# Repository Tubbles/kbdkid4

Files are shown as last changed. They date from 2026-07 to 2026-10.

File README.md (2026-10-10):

# kbdkid4

## Description

kbdkid4 is a split wireless keyboard, designed in [LibrePCB](https://librepcb.org).

Generated outputs (gerbers, BOM, schematic and assembly PDFs, STEP model) live in `output/v1/` and are also rebuilt by CI on every push, which publishes them as workflow artifacts and to [GitHub Pages](https://tubbles.github.io/kbdkid4/).

## 3D printed tray

`scripts/export_tray.py` builds a 3D-printable tray for the board from the exported STEP model, running FreeCAD headless. The board outline is located automatically (no hardcoded face indices); see the script's docstring for how and for the tray parameters.

    docker build -t freecad-headless -f scripts/freecad.Dockerfile scripts
    docker run --rm -v "$PWD":/work -w /work freecad-headless \
        freecadcmd scripts/export_tray.py --pass output/v1/kbdkid4_v1.step tray.stl [key=value ...] [flip]

The parameters (gap, wall, floor, depth, standoff and ledge dimensions) and their defaults are listed in the script's usage header and constants block.

`scripts/export_plate.py` likewise exports the switch plate: the kbdkid3 plate model (`resources/kbdkid3-plate-left.FCStd`), aligned onto the board by matching its switch cutouts to the board's switch grid, trimmed at the outer edges to fit the tray, extended over the microcontroller corner so it covers the whole board (with a conical recess on the underside at every soldered lead, 0.2 mm short of the top face, and a hole for the reset button), and cut with head-sized clearance holes at the board's mounting drills: the screws clamp the PCB onto the standoffs, the plate sits over their heads and is held down by the switches. The whole hole pattern (cutouts, screw holes, lead recesses, reset hole) is then shifted `pattern_shift` mm along +X relative to the outline, 0.25 mm by default: the first printed plates sat right in the tray but their holes drifted off the board's features toward the nice!nano side, and a plate printed with a 0.5 mm shift came out offset about as far the other way; the cause is still open. Last, `side_shave` mm (0.1 by default) comes off the plate's west and east edges, since the printed plate is a snug fit across the tray's width. The plate STL is written upside down (top face on the bed, lead recesses opening upward) so it prints as is without supports. CI exports both halves as the `plate-stl` artifact: `_Plate_Left.stl`, and `_Plate_Right.stl` mirrored across the board's center line (the word `right`).

CI runs this against the freshly generated STEP and uploads the result as the `tray-stl` workflow artifact.

CI exports both halves as the `tray-stl` artifact: `_Tray_Left.stl` as described, and `_Tray_Right.stl` built with the board's other side up (the word `right`), where the right half's switches and hotswap sockets sit, then turned over so it prints opening-up. That is not a mirror of the left tray: the right half's sockets do not reach the board edge, so that tray has no ledge notches.

## 3D printed PCB replica

`scripts/export_pcb.py` exports a printable stand-in for the bare board, for test-fitting the tray, plate, switches and screws before the fabricated boards arrive: the outline extruded to the board thickness with every drill hole, no components. Printed parts come out slightly larger than modelled, so the replica is pulled in by `pull_in` (default 0.2 mm) per side: the outline moves inward and every hole grows outward by that much. The thickness stays as modelled unless overridden with `thickness=`.

    docker run --rm -v "$PWD":/work -w /work freecad-headless \
        freecadcmd scripts/export_pcb.py --pass output/v1/kbdkid4_v1.step pcb.stl [right] [pull_in=0.2] [thickness=1.6]

CI uploads both halves as the `pcb-stl` artifact: `_Pcb_Left.stl`, and `_Pcb_Right.stl` mirrored across the board's center line (the word `right`). A bare board turned over would be its own mirror image, but a print is not: its bed side and its top side come out with different surfaces.

## License

See [LICENSE.txt](LICENSE.txt).

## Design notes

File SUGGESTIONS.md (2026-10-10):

# Suggestions

Ideas noticed during work, not yet asked for. Strike or promote as you see fit.

- **The nice!nano's board edge clears the tray ledge by only 0.03 mm.** With the nano under the board (`U1`, flipped), its PCB reaches to 0.63 mm inside the board's north edge, while the 1.0 mm ledge minus the 0.4 mm gap reaches 0.6 mm under the board edge (`scripts/export_tray.py`, `DEFAULT_LEDGE_WIDTH_MM`, `DEFAULT_GAP_MM`). The USB window removes the ledge over its 14 mm width, but the nano is 17.8 mm wide, so 2 mm at each end still face the ledge at 3.85 to 5.25 mm above the floor. Options: a narrower ledge (`ledge_width=0.9` or less), no ledge along that stretch, or the nano 0.3 mm further south on the board. Measured on LibrePCB's populated STEP export on 2026-09-27; not changed because it is a design choice between the ledge and the nano's position.
- **The west column's hotswap socket tabs end 0.17 mm from the tray wall.** Each PG1350 socket tab reaches 0.23 mm past the board outline (LibrePCB's placement of the package model, measured on the populated STEP export, 2026-10-08) and the wall sits `gap` = 0.4 mm outside the outline (`scripts/export_tray.py`, `DEFAULT_GAP_MM`). The ledge notches clear the tabs, but a print that comes out a little tight will rub there first. `gap=0.5` on the command line widens the whole cavity by 0.1 mm; the alternative is a shallow recess in the wall at the four notches. Left alone because the printed tray has not been tried yet.
- **The plate STL is not a closed mesh.** `scripts/export_plate.py` meshes the plate as a compound of touching cell solids (plus the tab and now the corner slab), so the STL carries coincident internal walls at every cell boundary: FreeCAD reports it non-manifold with hundreds of self-intersections, for the July 2026 export and the current one alike (the tray and PCB replica STLs are clean). Slicers have evidently coped so far. Fusing the solids once (`multiFuse` plus `removeSplitter`, which `drill_holes` already does for its connectivity check) before `export_stl` would give a single closed shell. Noticed 2026-10-08 while verifying the corner extension; left alone because it changes the shipped mesh of a part that already prints.
- **The printed plate's holes drift about 1 mm toward the nice!nano side over the plate's width; the cause is not found.** Checked 2026-10-09: `boards/board_1.1/board.lp` has every switch pitch at exactly 19.05 mm, the committed Excellon files put the 3.4 mm switch drills and the 2.4 mm mounting drills at the same positions, the kbdkid3 plate model's cutouts match the switch grid to 0.0005 mm, the exported plate STL has every cutout, screw hole and the reset hole at its design x within 0.08 mm, and the tray STL's standoff bores sit at the mounting drills to 0.001 mm. Both parts were printed unscaled. A 1 mm drift at 125 mm is 0.8 %, the size of a print scale or shrinkage error, but a plate shrunk that much should sit loose in the tray, which it does not. `pattern_shift` in `scripts/export_plate.py` corrects it empirically: a 0.5 mm shift came out offset about as far the other way (printed 2026-10-10; a linear 1 mm drift would have left both ends 0.5 mm off in opposite directions instead), so the default is 0.25 mm now. To find the cause, measure: the printed plate's width (design 135.05 mm for the plates printed so far, 134.85 mm since the side shave of 2026-10-10) and the span from the left edge of the bottom-left cutout to the right edge of the thumb cutout (design 128.4 mm), the PCB's two bottom mounting holes centre to centre (design 95.57 mm), and the printed tray's outer width (design 137.02 mm).

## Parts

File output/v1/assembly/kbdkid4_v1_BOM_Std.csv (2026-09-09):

Quantity | Designators | Package | Value | MPN | Manufacturer
50 | D100, D101, D102, D103, D110, D111, D112, D113, D120, D121, D122, D123, D130, D131, D132, D133, D140, D141, D142, D143, D150, D151, D152, D153, D163, D203, D210, D211, D212, D213, D220, D221, D222, D223, D230, D231, D232, D233, D240, D241, D242, D243, D250, D251, D252, D253, D260, D261, D262, D263 | SOD3717X135 | Diode SOD123
2 | DS1, DS2 | NICE_NICEVIEW | nice!view
2 | J1, J2 | JST_PH_S2B-PH-K_1x02_P2.00mm_Horizontal
54 | JP1, JP2, JP3, JP4, JP5, JP6, JP7, JP8, JP9, JP10, JP11, JP12, JP13, JP14, JP15, JP16, JP17, JP18, JP19, JP20, JP21, JP22, JP23, JP24, JP25, JP26, JP27, JP28, JP29, JP30, JP31, JP32, JP33, JP34, JP35, JP36, JP37, JP38, JP39, JP40, JP41, JP42, JP43, JP44, JP45, JP46, JP47, JP48, JP49, JP50, JP51, JP52, JP53, JP54 | SOLDER_JUMPER_2P
2 | S1, S2 | ALPSALPINE_SSSS811101 | SSSS811101
2 | S3, S4 | ESWITCH_TL3315NF100Q | Pushbutton Momentary NO (ESWITCH_TL3315NF100Q)
50 | S100, S101, S102, S103, S110, S111, S112, S113, S120, S121, S122, S123, S130, S131, S132, S133, S140, S141, S142, S143, S150, S151, S152, S153, S163, S203, S210, S211, S212, S213, S220, S221, S222, S223, S230, S231, S232, S233, S240, S241, S242, S243, S250, S251, S252, S253, S260, S261, S262, S263 | KHA-PG1350 | PG1350 Kailh Choc V1
2 | U1, U2 | NICE_NICENANO | nice!nano v2.0

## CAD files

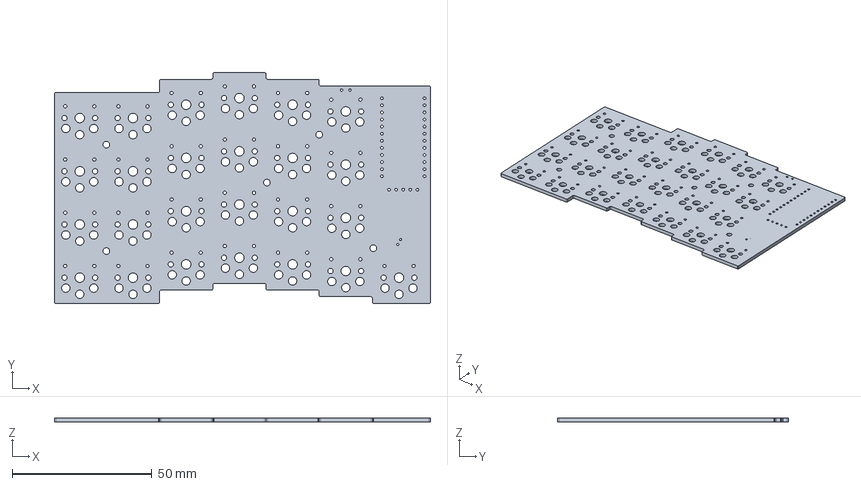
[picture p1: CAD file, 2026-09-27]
output/v1/kbdkid4_v1.step
134.6 x 82.6 x 1.60 mm

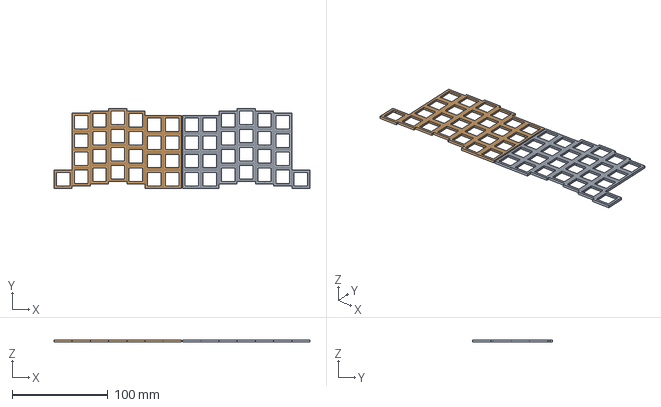
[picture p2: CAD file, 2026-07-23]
resources/kbdkid3-plate-left.FCStd
268.0 x 83.3 x 2.20 mm
PointArray
PointArray (Mirror #1)

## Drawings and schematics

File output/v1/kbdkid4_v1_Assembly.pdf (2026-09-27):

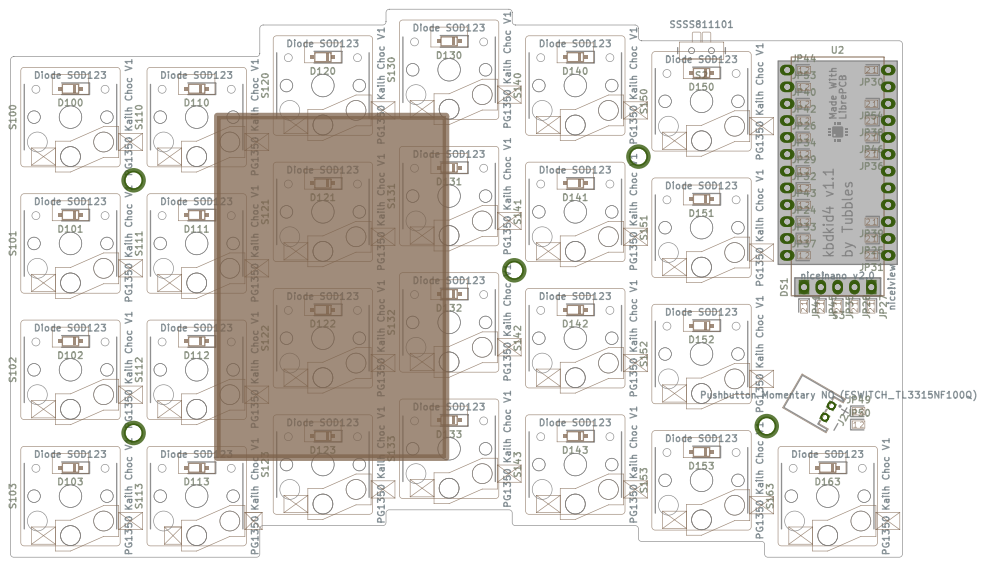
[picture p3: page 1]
Made With; kbdkid4 v1.1; by Tubbles; PG1350 Kailh Choc V1

PG1350 Kailh Choc V1

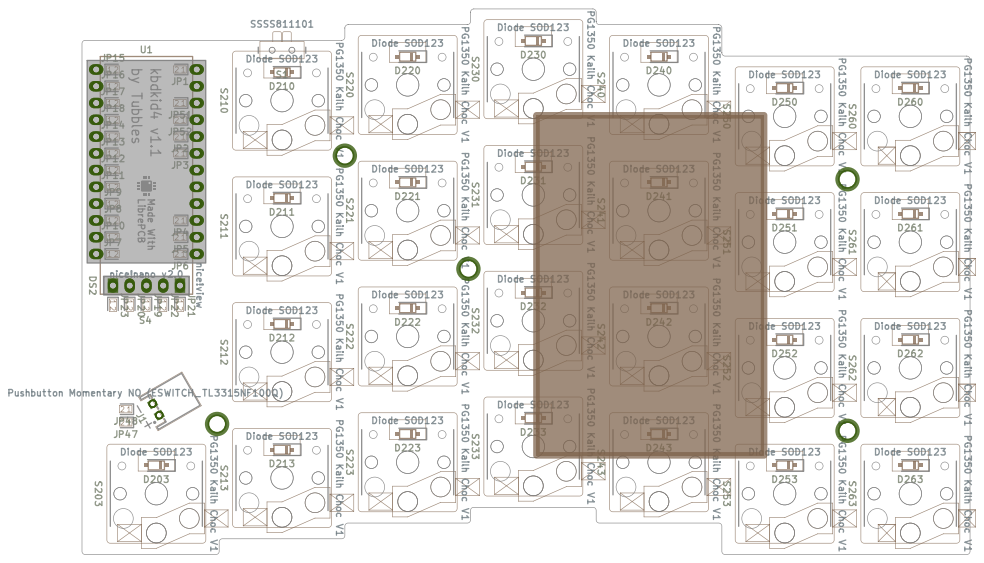
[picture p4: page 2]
PG1350 Kailh Choc V1; Made With; LibrePCB -; + kbdkid4 v1.1; by Tubbles

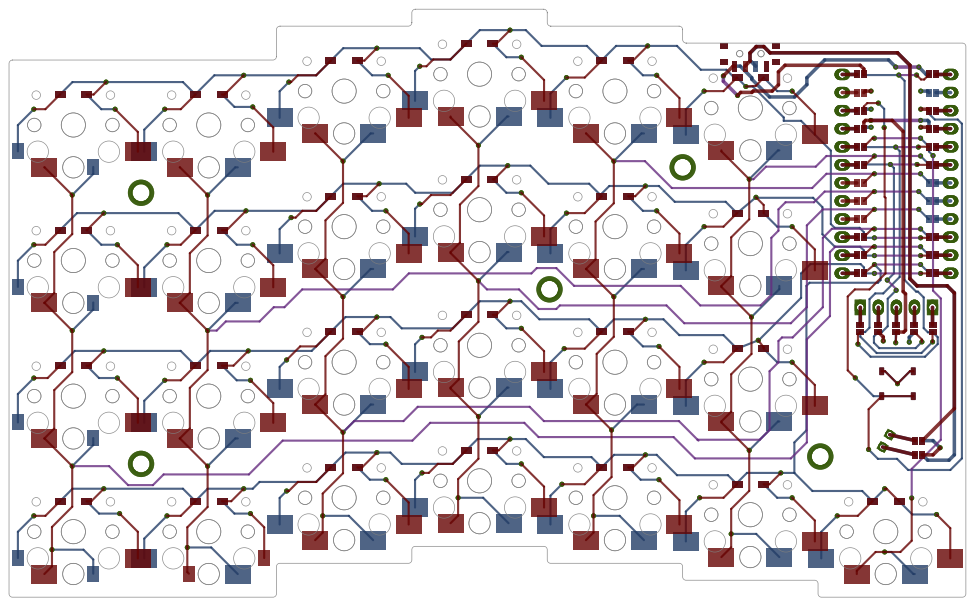
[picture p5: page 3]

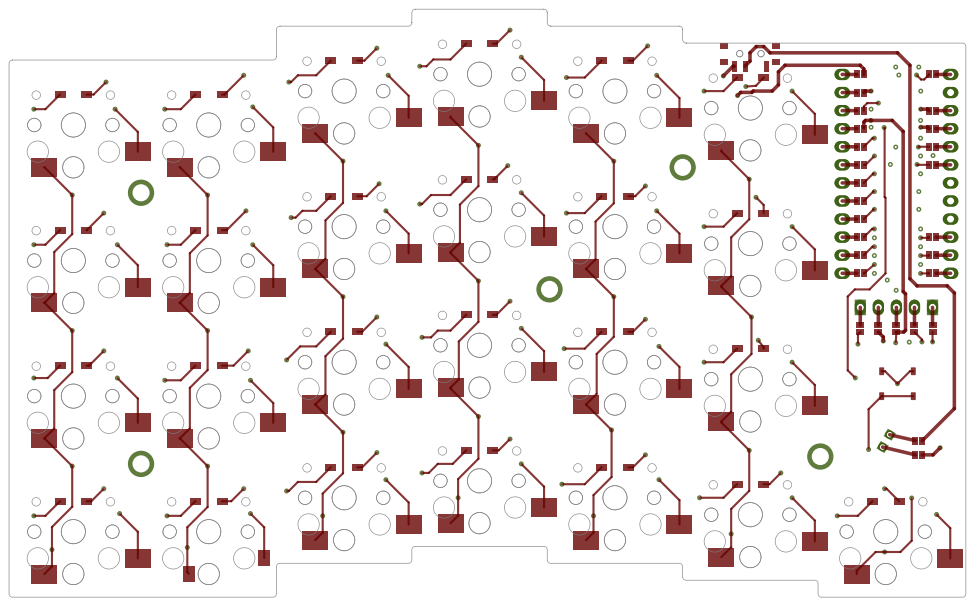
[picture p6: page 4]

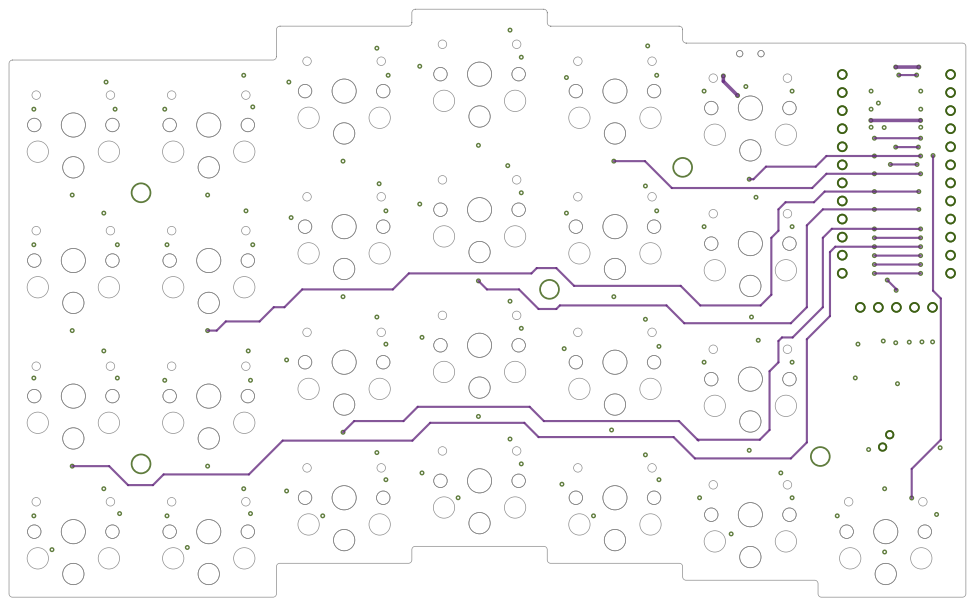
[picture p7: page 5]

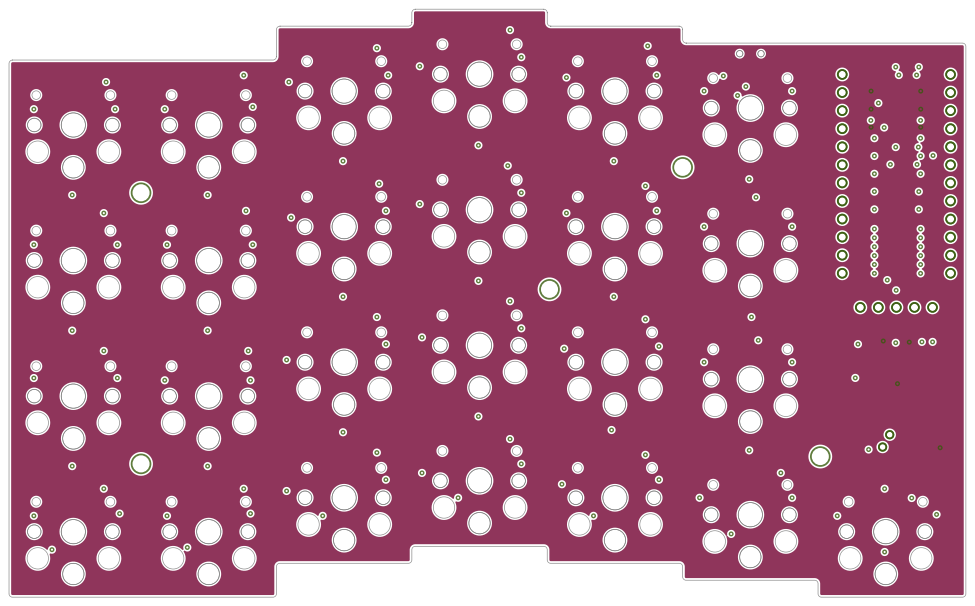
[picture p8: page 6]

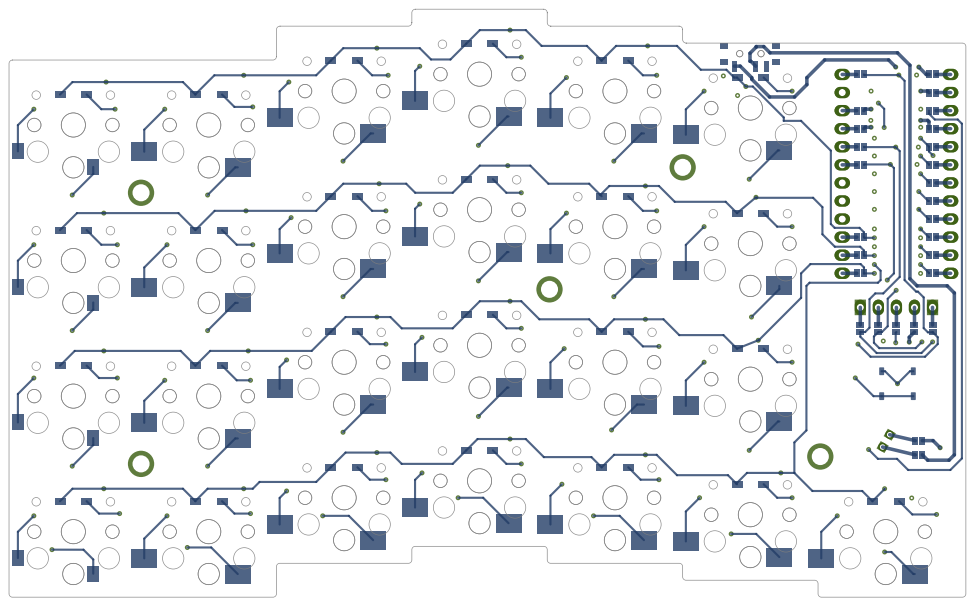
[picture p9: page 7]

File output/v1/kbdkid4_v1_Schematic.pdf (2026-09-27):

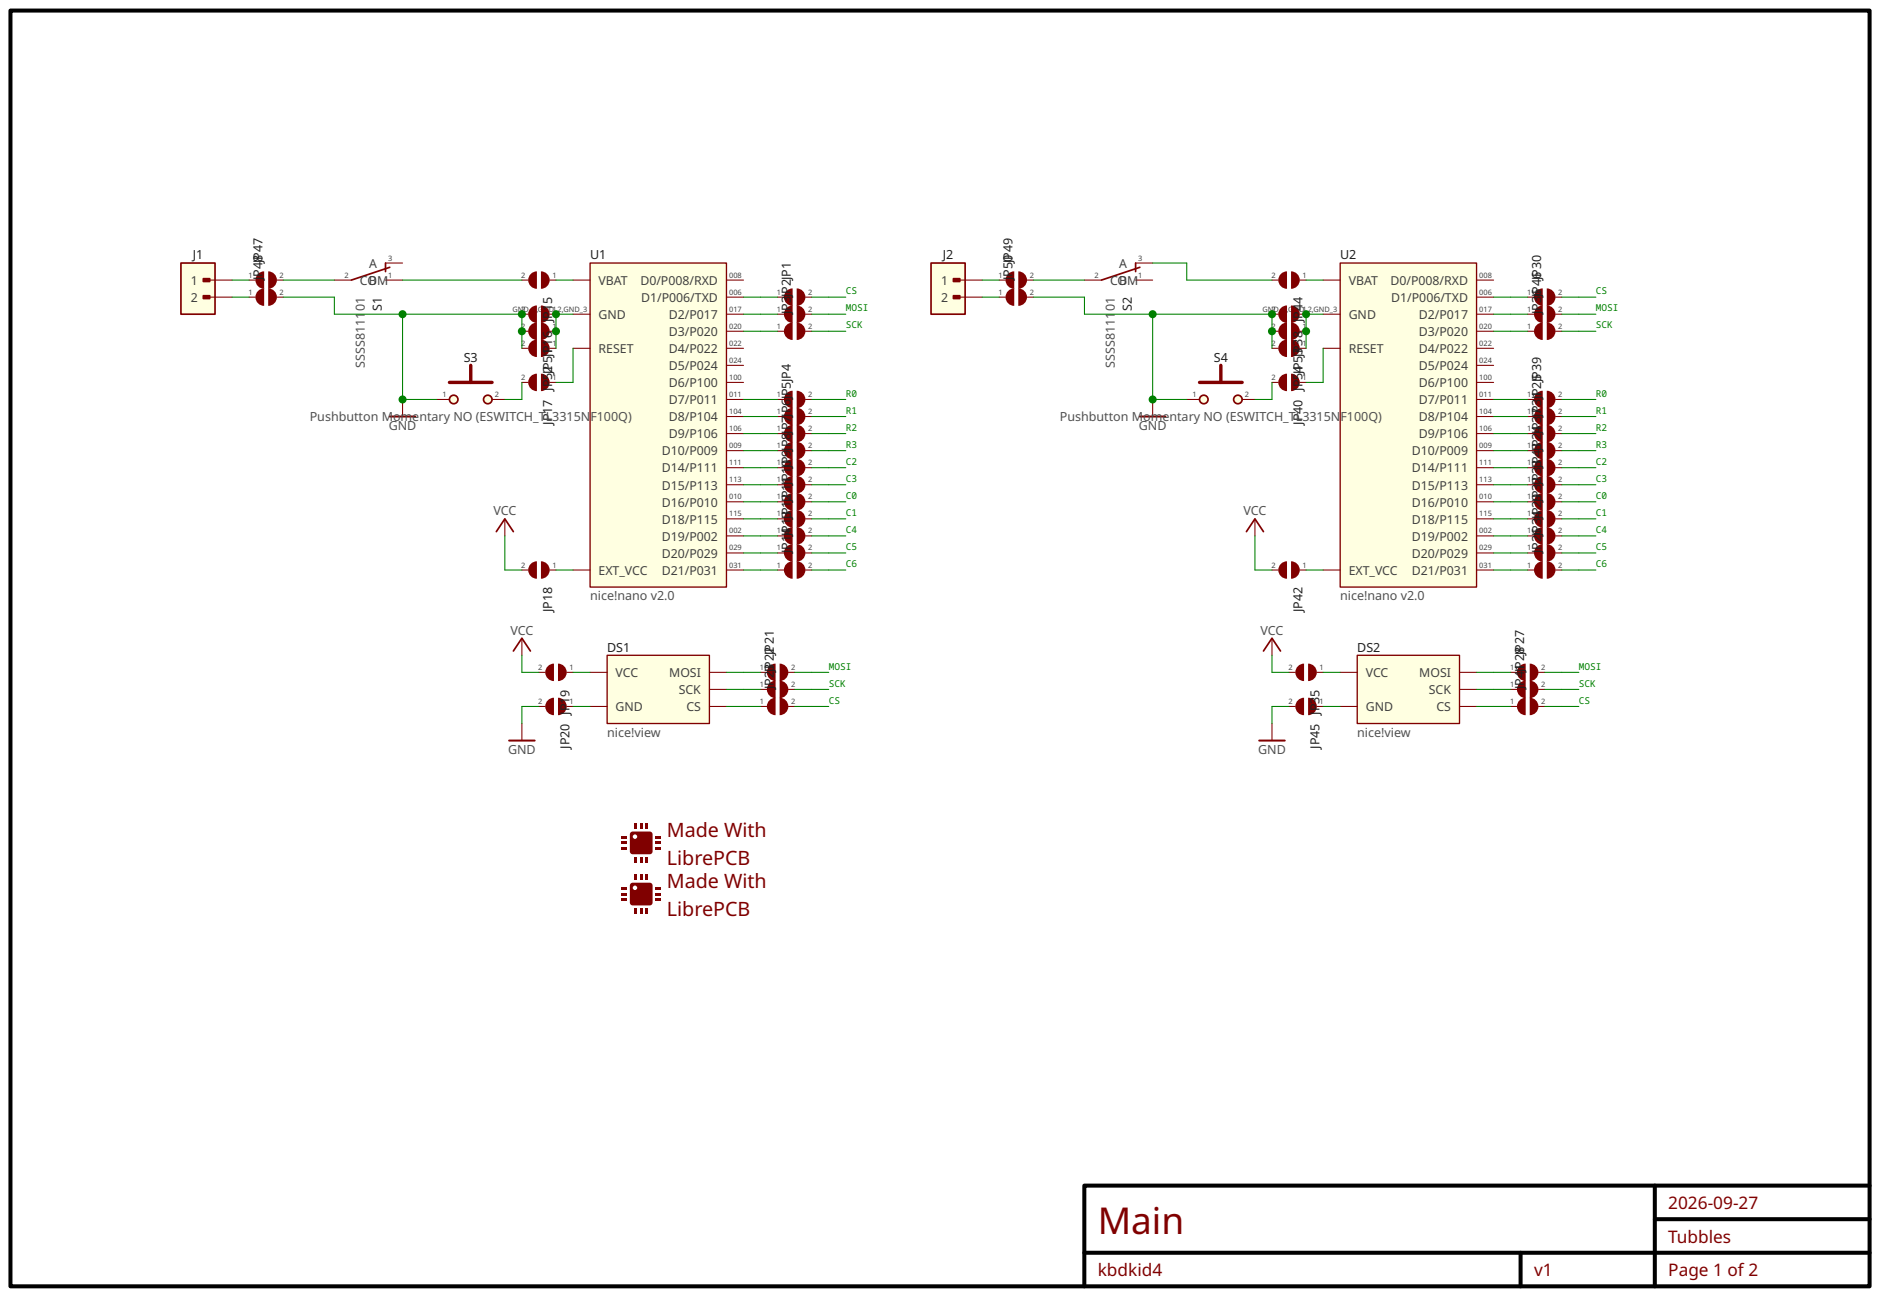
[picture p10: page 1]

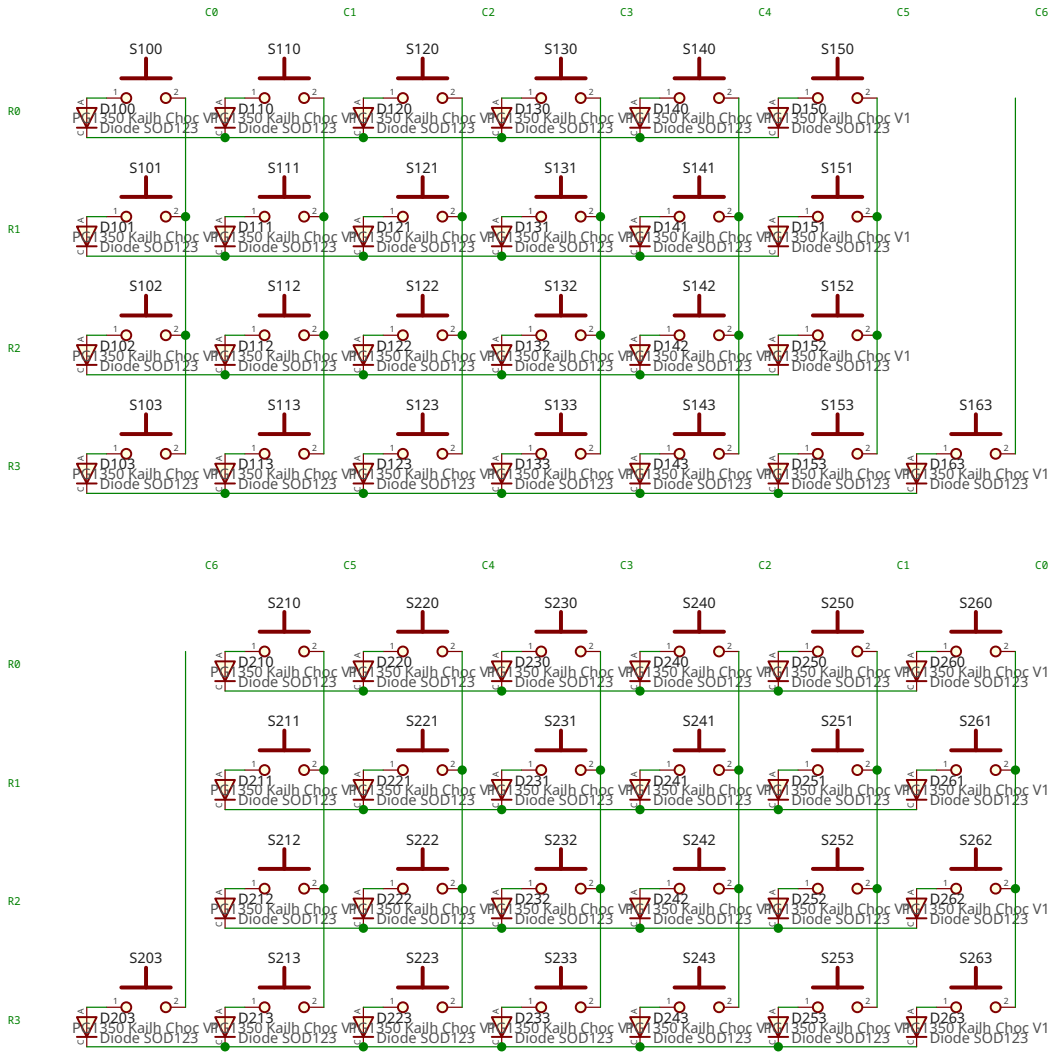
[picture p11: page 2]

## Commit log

2026-07-10 Rev 1
    [kbdkid4_v1_BOM_Std.csv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]
2026-07-22 Add headless FreeCAD tray export script and CI job
    The board is located by the label LibrePCB gives the board body in
    STEP exports, a hardcoded constant in LibrePCB's stepexport.cpp,
    validated geometrically with a geometry-only fallback.
    Gotchas that shaped the script, all observed on FreeCAD 1.0.0 from
    Debian trixie: freecadcmd exits 0 even when the script raises, runs
    the script with __name__ set to the file stem, may run it twice, and
    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
2026-07-22 Give all outer shell corners one uniform fillet radius
    The board outline's corners come pre-rounded from the PCB design, so
    chained offsets can never produce equal radii. The outline is instead
    rebuilt as a sharp-corner polygon, offset with sharp joins, and the
    extruded shell's vertical edges are filleted before the cavity cut.
    The cavity keeps the plain offset geometry so the board clearance
    stays constant.
    The radius is gap + wall, capped by what the shortest outline step
    can fit. A fillet consumes R * tan(turn / 2) of each adjacent edge
    and the column stagger steps are only 2.381 mm long, which makes
    OpenCASCADE fail at the nominal 1.2 mm. This board lands on 1.13 mm.
    Verified by counti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
2026-07-22 Round the cavity's sharp corners to keep the wall width constant
    Where the outline is concave, offsetting trims the cavity wall to a
    sharp corner while the outer shell gets a cove fillet, so the wall
    locally ballooned to about 1 mm. A fillet of outer radius plus wall
    thickness is concentric with the cove and restores the nominal width
    at any corner angle.
    The sharp edges are found as the only vertical line edges left with a
    real dihedral angle after the shell fillets. Tangent seam edges must
    be skipped, OCC cannot fillet those. At seven of the nine corners
    on this board the fillet overruns the short stagger step wall into
    the neighbouring corner arc, so OCC emits blend surfaces instead of
    c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
2026-07-22 Build the cavity concentric with the shell for constant wall width
    The cavity previously followed the board outline's own corner rounds,
    so at convex corners its arc was not concentric with the shell's
    uniform fillet and the wall swelled to about 0.63 mm mid corner. The
    cavity is now built from the same sharpened polygon as the shell
    and its corners are filleted with the concentric counterparts of the
    shell radius: outer radius minus wall on convex corners, plus wall
    on concave ones. The fillet centers coincide for any corner angle,
    which is what makes the wall width exact rather than approximate.
    This replaces the previous post-cut patch for sharp cavity corners.
    Filleting the cavity prism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
2026-07-22 Give every corner the same bend radii and consolidate the constants
    Convex corners bent with radii 0.73 and 1.13 mm while concave
    ones bent with 1.13 and 1.53 mm, so concave corners looked visibly
    rounder. Every bend now carries the corner radius on its outside
    and corner radius minus wall on its inside regardless of direction,
    which means the shell's concave coves and the cavity's concave arcs
    both shrink by one wall thickness. Growing the convex corners to match
    the old concave ones instead would not fit the 2.381 mm stagger steps,
    so this is also the only feasible direction. The concentric pairing
    and the constant wall width are unchanged.
    The face census now shows exactly two radii, 25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
2026-07-22 Add insert standoffs at the board's mounting drills
    Each standoff is a cylinder rising from the tray floor, bored for an
    M2 heat-set insert (CNC Kitchen style), placed at the board's 2.4 mm
    mounting drills. The drills are detected from the STEP geometry as
    full-circle cylinder faces of that diameter along the board normal
    rather than assumed: the full-circle test excludes outline corner
    arcs and the diameter tolerance excludes the board's other drills
    (0.3, 0.5 and 2.0 mm). The board source lists five such holes and
    the detection finds exactly those five, at matching coordinates.
    The bore's floor is the tray floor's top surface, so the floor
    thickness of material backs the insert, and the s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
2026-07-22 Tighten the PCB clearance gap from 0.8 to 0.6 mm
    With gap + wall now at 1.0 mm the corner radius target binds instead
    of the outline fit cap (1.13 mm), so every bend becomes 0.6 mm inside
    and 1.0 mm outside. The footprint shrinks by 0.4 mm per axis.
    Also replace the hardcoded parameter list in CLAUDE.md's tray command
    with a pointer to the script's constants block, the same as README
    already does, so default changes cannot leave it stale.
    Assisted-by: Claude:claude-fable-5
2026-07-22 Deepen the tray and thicken its walls and floor
    New defaults: gap 0.2 mm, wall 0.8 mm (two nozzle widths), floor 1.2
    mm, height 14.1 mm. Standoffs stay at 8.0 mm.
    Since gap + wall still totals 1.0 mm the footprint and the outside
    corner radius are unchanged, but the inside of each bend tightens
    to 0.2 mm. The cavity is now 12.9 mm deep, so the walls rise 3.3 mm
    above the top face of a board resting on the standoffs.
    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
2026-07-22 Drive the tray by cavity depth instead of overall height
    The user-facing constant is now the cavity depth from the floor's
    top to the rim, with the overall height derived as depth + floor. The
    default of 12.9 mm keeps the built geometry identical to before (14.1
    mm overall). The key=value override is now depth instead of height.
    Also replace the stale hardcoded parameter example in the module
    docstring with a pointer to the USAGE text and constants block.
    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
2026-07-22 Widen the PCB clearance gap from 0.2 to 0.4 mm
    With gap + wall back at 1.2 mm the outline fit cap binds again, so
    every bend becomes 0.33 mm inside and 1.13 mm outside. The footprint
    grows by 0.4 mm per axis.
    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
2026-07-22 Record project conventions learned while building the tray
    Adds to CLAUDE.md: the commit-and-push-without-asking convention, the
    role of board.lp as design ground truth for cross-checking what the
    script detects from the STEP, and how to inspect geometry by exec'ing
    the script with its trailing run_and_exit() call stripped (a plain
    import would run main and exit the interpreter). Also mentions the
    insert standoffs in the tray script's description.
    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
2026-07-22 Add a PCB support ledge along the cavity wall
    The ledge is a shelf as tall as the standoffs so the board rests on
    both, protruding ledge_width from the cavity wall into the cavity.
    Since the wall sits gap away from the board edge the shelf reaches
    ledge_width minus gap under the board perimeter, 0.6 mm at the
    defaults; ledge_width at or below gap is therefore rejected, and 0
    disables the ledge. The ledge ring reuses the shell's outer boundary
    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
2026-07-23 Add the kbdkid3 switch plate model for reuse
    Copied unchanged from the kbdkid3 project (designed and printed in
    2023). One FreeCAD document holds a parametric 19 x 19 mm switch
    cell replicated by a point array into the left plate, plus a mirrored
    right plate. It shares the kbdkid4 board's coordinate frame, and all
    five kbdkid4 mounting positions land on plate material, so it can be
    reused with drilled holes instead of redesigning the plate.
    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
    [kbdkid3-plate-left.FCStd]
2026-07-23 Extract shared board and freecadcmd helpers into board_step.py
    Board location, mounting drill detection, STL meshing and the
    freecadcmd scaffolding move out of the tray script so a plate export
    script can reuse them. Unlike the export scripts the module has
    no entry point call, so probes can import it normally. Behavior is
    unchanged: the tray build produces the identical volume and facet
    count as before the split.
    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
2026-07-23 Export the switch plate with drilled mounting holes
    Plain 2.4 mm through holes are drilled into the reused kbdkid3 plate
    at the board's mounting drills, detected from the STEP the same way
    the tray places its standoffs, so the plate always tracks the PCB.
    Only the left plate is exported; the right half is mirrored in the
    slicer, like the tray.
    The script prints per hole how much plate material surrounds it and
    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
2026-07-23 Add a plate variant with screw head clearance holes
    For the stack where the screws clamp the PCB onto the standoffs and
    the plate sits above them: the "heads" word drills for the measured
    3.77 mm screw head plus 0.4 mm clearance instead of the thread. CI
    exports both variants so they can be tried side by side, as _Plate.stl
    and _PlateOverScrews.stl in the plate-stl artifact.
    The larger drill severs the 1 mm web north of the partially supported
    hole, splitting that cell solid in two. Both pieces stay in contact
    with the plate, but since drilling can evidently sever webs, the
    script now also verifies that all pieces fuse into one connected part,
    so a floating fragment can never reach a printe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
2026-07-23 Align the plate to the board's switch grid and trim its edges
    The kbdkid3 plate does not share the kbdkid4 board's origin, so the
    drilled holes missed the PCB drills. The script now measures the
    offset instead of assuming a shared frame: it matches every switch
    cutout center in the plate against the board's key switch positions,
    parsed from board.lp joined with circuit.lp by component UUID (the STEP
    carries no switch bodies). All 25 cutouts agree on a translation of
    (-1.111, -0.318) mm with zero residual; anything but a pure translation
    within 0.05 mm is rejected.
    The outer silhouette is then trimmed 0.6 mm on all edges. Aligned but
    untrimmed, the plate interfered with the tray cavity on tw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
2026-07-23 Cut the screw clearance even at mostly open positions
    Skipping low-support positions was wrong: 7 percent overlap still
    means a sliver of plate material protrudes into the screw's path and
    would collide with the shaft, or with the head in the heads variant.
    Every position is now cut; where it sits mostly in open plate area
    the cut is a clearance cutout rather than a supported hole, and the
    support threshold only affects how the printout describes it. Frame
    mismatch, the original reason for refusing low support, is already
    excluded by the switch grid alignment check.
    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
2026-07-23 Lower the tray rim 1 mm and enlarge the plate 0.2 mm per side
    With the plate resting on the board top at 9.6 mm, its top face ends
    at 11.8 mm and the rim now lands at 11.9 mm, so plate and wall line
    up. The plate's edge trim goes from 0.6 to 0.4 mm, which leaves 0.32
    to 0.48 mm of cavity clearance on the close sides.
    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
2026-07-23 Reach the USB notch further past the shared corner
    A spike of wall about 0.2 x 0.4 mm survived between the two notches
    at the outer corner: the rectangular cutters' end faces meet at 49
    degrees, and the outer corner wedge extends about 1.3 mm past the
    corner, beyond both end faces. The 1.0 mm shared corner reach was not
    enough; 2.5 mm swallows the wedge, and the extended cutter touches
    no wall outside the already open region since the nearest intact wall
    lies outside its band.
    Verified on the exported STL this time, with a dense grid map of the
    corner neighbourhood rather than a single sample line, which is how
    the earlier check missed the spike.
    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
2026-07-24 Slope the wall into the notch ends and round the crests
    At the merged opening's two outer ends the neighbouring wall now
    descends into the notch over a 3.2 mm ramp (45 degrees at the notch
    depth) instead of stopping at a vertical step, and the crest where
    the full-height rim meets the slope is rounded with a 1 mm fillet.
    The fillet is attempted per crest and reported; a refusal from OCC
    leaves that crest sharp rather than failing the build.
    The wall bends through corner arcs within both ramps, so the ramp
    cutters use a widened band across the wall, and verification probes
    the actual bent wall paths: the right edge wall descends 11.9 to
    10.9 approaching the switch end and the top edge wall 1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
2026-07-25 Note the schematic and routing tools in the skill
    Verified by building a two-net board without opening the GUI at all:
    create, import a library element, instantiate it, wire the schematic,
    place, route. The result passes open-project --strict with a clean ERC.
    The autorouting caveat is from experience rather than
    caution. Re-routing a net across layers on this board with a straight
    trace produced five genuine clearance violations, because the tools
    put copper exactly where they are told and have no idea what is
    already there.
    Assisted-by: Claude:claude-opus-5
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2026-07-25 Note the DRC clearance locator in the skill
    librepcb-cli --drc names the rule that broke but never the coordinates,
    so every violation starts with a hunt. The locator measures the board
    geometry directly and names both objects and the gap.
    It approximates: straight segments only, pads as their circumscribed
    circle, and no knowledge of planes, arcs or DRC approvals. On a board
    with approvals it will list them all, hence the --net filter. It is
    for finding things, never for deciding whether the board is clean.
    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
2026-09-09 update output jobs
    [kbdkid4_v1.step, kbdkid4_v1_BOM_Std.csv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]
2026-09-09 try out the push and shove router, re-add naked pcb .step
    [kbdkid4_v1.step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]
2026-09-26 finished v1.1
    [kbdkid4_v1.step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]
2026-09-26 Resolve the board file through boards.lp
    The board directory was renamed from default to board_1.1 in
    "update output jobs" (9491f33) and the export scripts still opened
    boards/default/board.lp, which is what has been failing the tray CI
    job since. The first board listed in boards.lp is what LibrePCB's
    output jobs mean by "(board default)" (OutputJobRunner::getBoards
    takes getBoardByIndex(0)), so the scripts now follow the same rule
    instead of a fixed path.
    Rotation and flip are parsed alongside the position, mapped in the
    order LibrePCB's Transform::map uses (mirror, rotate, translate). The
    tray needs that to locate the nice!nano's connector end on the new
    outline.
    Assisted-by: Claude:clau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
2026-09-27 Fix DRC
    [kbdkid4_v1.step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]
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2026-10-08 Extend the plate over the microcontroller corner
    With the nice!nano and the power switch on the board's underside and
    the nice!view left off, the top right corner of the left half is bare
    board, so the plate now covers it. The slab's inner boundaries are the
    switch column's east edge and the thumb cell's top edge, read off the
    plate silhouette after trimming, and it abuts them without overlapping,
    the way the cells abut each other. Its outer boundary is the outline
    plus 0.35 mm, the same 0.05 mm short of the tray wall as the tab.
    What stands up in that corner are the soldered leads of the
    through-hole parts underneath (24 nice!nano pins, 2 battery connector
    pins, and the 5 unused nice!view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
2026-10-09 Drop the plate variant with thread-sized holes
    The plate is held down by the switches, as it always has been
    in practice, with the screws clamping the PCB onto the standoffs
    underneath it. So the head-clearance holes are the only kind the
    plate needs and the "heads" word and the second CI run go away;
    hole_diameter= stays as the override, now defaulting to the measured
    3.77 mm head plus 0.4 mm.
    Claude-Session: https://claude.ai/code/session_01Qx6CgV6EKWaE5USumytjG4
    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
2026-10-09 Shift the plate's hole pattern 0.5 mm toward the nice!nano side
    The first printed plates sit right in the tray but their holes drift
    off the board's features toward the right, about a millimetre by
    the thumb key, the reset button and the rightmost screw. The design
    files do not explain it: every switch pitch in board.lp is exactly
    19.05 mm, the committed drill files repeat the same positions, the
    kbdkid3 plate's cutouts match the switch grid to 0.0005 mm, and the
    exported STL has every hole at its design x within 0.08 mm. Until
    the cause turns up (SUGGESTIONS.md lists the measurements that would
    find it), a shift of half the drift splits the error, and that is
    what pattern_shift does, 0.5 mm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
2026-10-10 Halve the plate's hole pattern shift to 0.25 mm
    A plate printed with the 0.5 mm shift came out with its holes offset
    about as far the other way as the unshifted plate's were. A linear
    drift of 1 mm across the plate would have left both ends 0.5 mm off
    in opposite directions instead, so the mismatch looks more like a
    uniform offset of about a quarter millimetre. The cause is still open,
    SUGGESTIONS.md keeps the measurements to take.
    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
2026-10-11 Record the populated board's tray clearances
    The soldered board does not seat cleanly in the printed tray. A fit
    check of LibrePCB's populated STEP export against the trays the
    export builds finds no interpenetration at nominal dimensions; the
    clearances a print's swelling has to fit into are 0.03 mm (nano to
    the north ledge), 0.17 mm (west socket tabs to the wall) and 0.38 mm
    (bottom-row sockets to the south ledge). The numbers and the
    candidate relief cuts replace the two earlier bullets that covered
    the nano and the tabs alone.
    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
2026-10-11 Relieve the tray ledge where underside bodies come too close
    The soldered board would not seat: the nice!nano's north edge sits 0.03
    mm from the ledge and its east edge 0.27 mm, the bottom-row sockets
    0.38 mm, all within what a printed inner face swells by. Rather than
    narrowing the ledge everywhere, the export now cuts it away only beside
    bodies that come within relief_clearance (0.5 mm) of its inner face,
    over the body's extent along that wall and down to the body's reach
    plus 0.5 mm, so the rest of the ledge keeps supporting the board. The
    socket tabs keep their 3 x 3 mm notches; a tab's relief finds nothing
    left to cut inside them, but it catches the right half's S253 tab
    0.15 mm from th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
2026-10-12 Shrink the plate's reset hole to a 1.5 mm pin hole
    The reset switch fitted is a 4.5 x 4.5 x 0.55 mm micro tactile switch,
    pressed with a SIM ejector pin, so the 10 mm opening only exposed the
    board. The plate keeps a 6.15 x 5.6 mm pocket over the switch (pads
    plus 0.5 mm per side), 1.0 mm deep from the underside, which leaves
    1.2 mm of plate to guide the pin. It applies to every plate variant,
    and the right half's S4 shares S3's position and symmetric footprint,
    so the mirror needs nothing extra.
    The pocket sits 3.12 mm from the nearest lead cone, and the right
    half's S4 at S3's spot along the same axis. A 1.5 mm hole tolerates
    no layout drift the way the 10 mm one did, so the export checks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
2026-10-12 Hug the left half's USB-C receptacle with a smaller rounded window
    On the soldered left half the receptacle's mouth sits only 0.56 mm
    behind the tray's outer face, so the wall no longer needs room for a
    plug overmold to reach in. The window is the old 14 x 8 mm one with
    its edges pulled in by what the user measured around the connector
    on the first print: 10.5 x 4.5 mm. Its own constants hold it, so
    retuning the right half's window later cannot move it. The 1.95 mm
    corner radius is the shell's 1.28 mm (package model) plus the 0.67 mm
    vertical clearance, so the corners run concentric with the shell's. A
    0.2 mm chamfer on both faces gives the taper.
    The right tray is untouched and byte-identi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
2026-10-12 Hang the tray's nano reliefs at the measured nano depth
    The nano package model gets the depth wrong: it has a 1.4 mm board
    on 2.75 mm of sockets with the receptacle straddling it, reaching
    4.93 mm below the board. Measured on the soldered left half (user,
    2026-10-12): the nano sits flush on Mill-Max sockets (2.56 mm on the
    left, 4.3 mm planned on the right), its board is 1.6 mm thick and the
    receptacle is flush with its underside. So the nano and its connector
    both reach socket height plus 1.6 mm below the board.
    On the right half the reliefs now reach 1.75 mm deeper, 0.5 mm below
    the nano's underside. The model's depth would have left the nano's
    lowest 1.25 mm against the ledge, binding li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
2026-10-12 Clear the tray's last tight spots around socket tabs and standoffs
    A fit check of LibrePCB's populated STEP export against both trays
    left the west socket tabs 0.17 mm from the wall inside their ledge
    notches, under the roughly 0.2 mm per side a print swells, and three
    bodies 0.50 to 0.76 mm from a standoff (sockets S150 and S141, the
    battery connector). After this change the tabs are 0.50 mm from the
    wall and those bodies 1.00 to 1.04 mm from the standoffs.
    The standoffs get 1.0 mm, not the 0.5 mm the ledge reliefs use:
    at 0.5 mm only S150 would get a flat, 0.01 mm deep, and they have
    1.3 mm of plastic around the insert bore to spare. A flat refuses to
    leave less than 0.6 mm. The deepest o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
2026-10-12 Leave three print layers over the covered plate's diode pit
    The pit stopped 0.2 mm short of the top face like the lead recesses,
    so a single layer bridged it, and across a 6.25 x 2.56 mm pit that
    layer printed translucent. D123 measures 1.14 mm tall on the soldered
    board, so a 1.6 mm deep pit still clears it by 0.46 mm and leaves
    0.6 mm, three 0.2 mm layers, of the 2.2 mm plate over it.
    Assisted-by: Claude:claude-opus-5-5
    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
2026-10-13 Drop the plate's lead recesses for the unfitted nice!view header
    The nice!view is not fitted for now, so its five header drills have
    no leads to clear. The right half's DS2 uses the same five drills as
    DS1. The export fails unless every one of DS1's header pads has its
    drill among the lead drills, so a moved footprint cannot silently
    bring the recesses back.
    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
2026-10-13 Widen the plate's reset pin hole to 3.0 mm
    The hole stays inside the reset switch's 6.15 x 5.60 mm pocket, so
    the pocket's clearance check against the lead recesses still covers
    it.
    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
2026-10-15 Share the closed-mesh check between the export scripts
    The solder spool axle export needs it too. A failing plate export now
    says "the mesh is ..." instead of "the plate mesh is ...", still naming
    the removed file.
    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
2026-10-17 Add a Pi camera arm for the Ender 3 V2's right base rail
    The arm stands behind the right upright: in front of it the gantry's
    right end and the Klipper host Pi leave about 5 mm of rail. It fixes
    with a printed twist-in T-nut around an M3 nut, since no extrusion
    T-nuts are on hand, and the case closes with M2 heat-set inserts.
    Creality publishes no CAD for the V2, so the rail, slot and bed
    figures come from its Ender-3 STEP. The rail behind the upright, the
    bed's height over the rail and the slot neck are unverified on the V2.
    The camera board's thickness and component heights are assumed, since
    the official drawing gives none.
    From behind the upright the gantry hides a band of the bed: abo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
2026-10-17 Document the camera arm's assembly order and probe the arm
    The case sits over the base bolt, so the arm goes on the rail first.
    Loose on the slot floor the T-nut cannot turn: the M3 nut's corners
    sit where the taper leaves 6.22 mm for its 6.35, so the bolt lifts it
    against the lips before it is turned. The old ear screw access check
    pointed away from every obstacle and could not fail.
    The STLs are byte-identical to 053755b's.
    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
